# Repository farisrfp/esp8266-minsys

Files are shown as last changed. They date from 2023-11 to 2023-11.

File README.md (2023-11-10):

# **ESP8266 Minimum System**

_Workshop Telematika 2023_

Teknik Komputer ITS

## **Deskripsi**

Dokumentasi ini dibuat untuk memudahkan peserta workshop dalam memahami dan mengembangkan ESP8266 Minimum System pada Workshop Telematika 2023.

Diagram Fitur ESP8266 Minimum System dan PCB dapat dilihat pada gambar berikut.

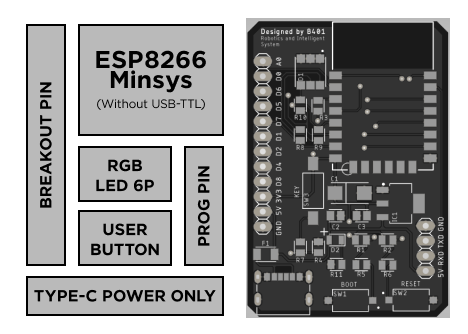
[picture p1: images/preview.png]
ESP8266 Minimum System


## Hardware

Gambar dibawah merupakan design hardware ESP8266 Minimum System yang akan digunakan pada workshop.

<table>
                <tr>
                    <th>Jalur PCB</th>
                    <th>Hasil Gerber</th>
                    <th>Gambar 3D</th>
                </tr>
                <tr>
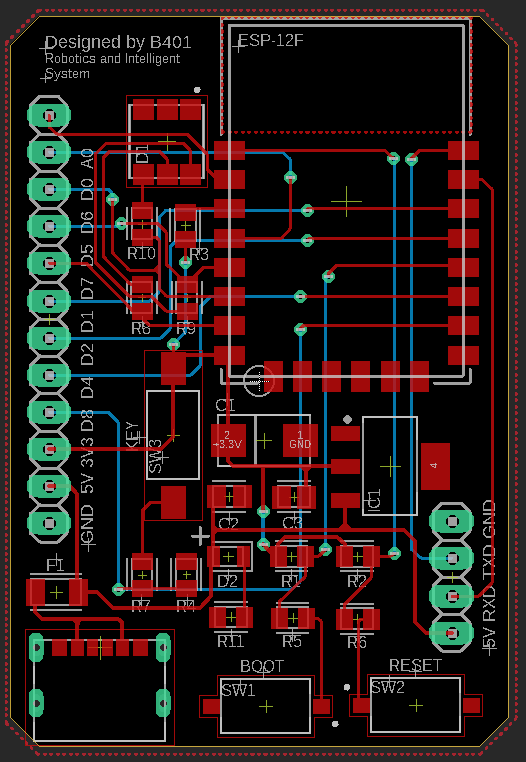
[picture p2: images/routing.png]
                    <td></td>
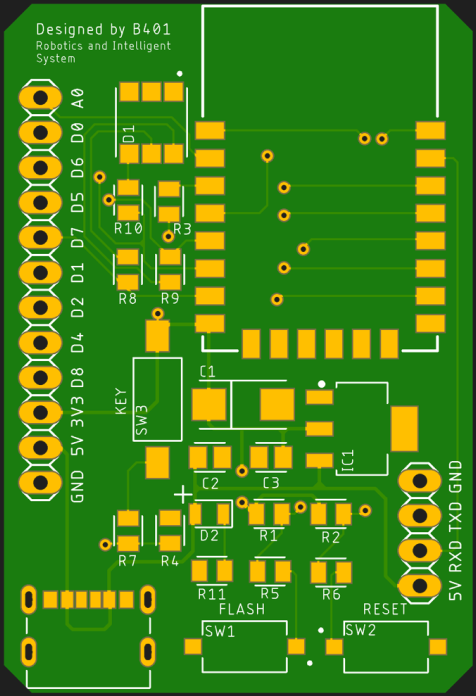
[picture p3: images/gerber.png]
                    <td></td>
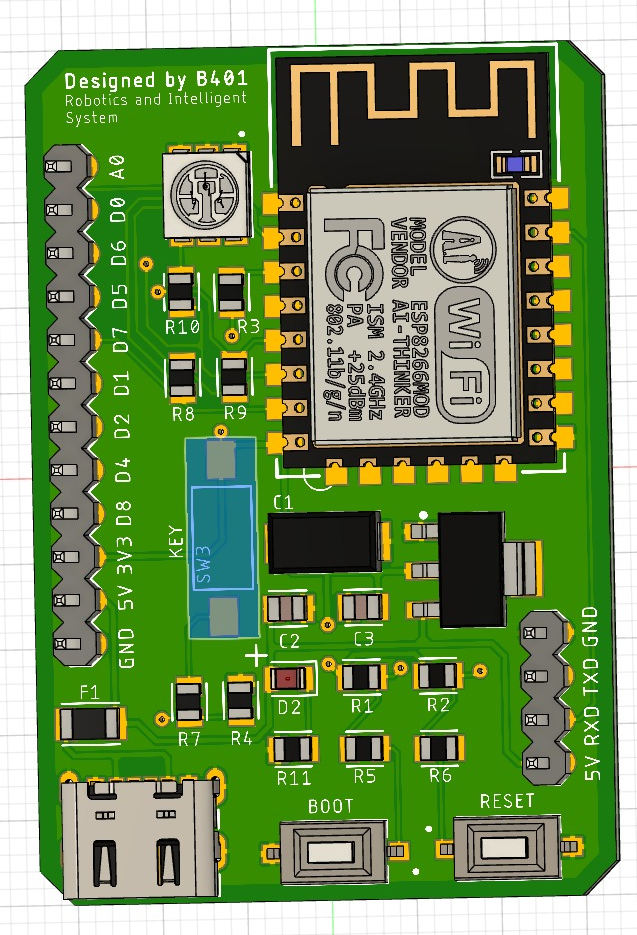
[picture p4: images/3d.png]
                    <td></td>
                </tr>
</table>

Untuk dokumentasi hardware, silahkan lihat [/hardware](hardware/readme.md)

## Firmware

Untuk dokumentasi firmware, silahkan lihat [/firmware](firmware/readme.md)

## Kontribusi

Kami sangat terbuka terhadap kontribusi dari semua pihak. Jika Anda ingin berkontribusi dengan memperbaiki atau melengkapi template ini, silakan buat pull request ke repositori template kami.

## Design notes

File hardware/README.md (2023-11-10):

# **Dokumentasi Hardware**

## Software

- [Eagle](https://www.autodesk.com/products/eagle/overview) (Untuk membuka file .sch dan .brd)
- [Fusion 360](https://www.autodesk.com/products/fusion-360/overview) (Alternatif)

## Schematic

Gambar dibawah merupakan schematic ESP8266 Minimum System yang akan digunakan pada workshop.

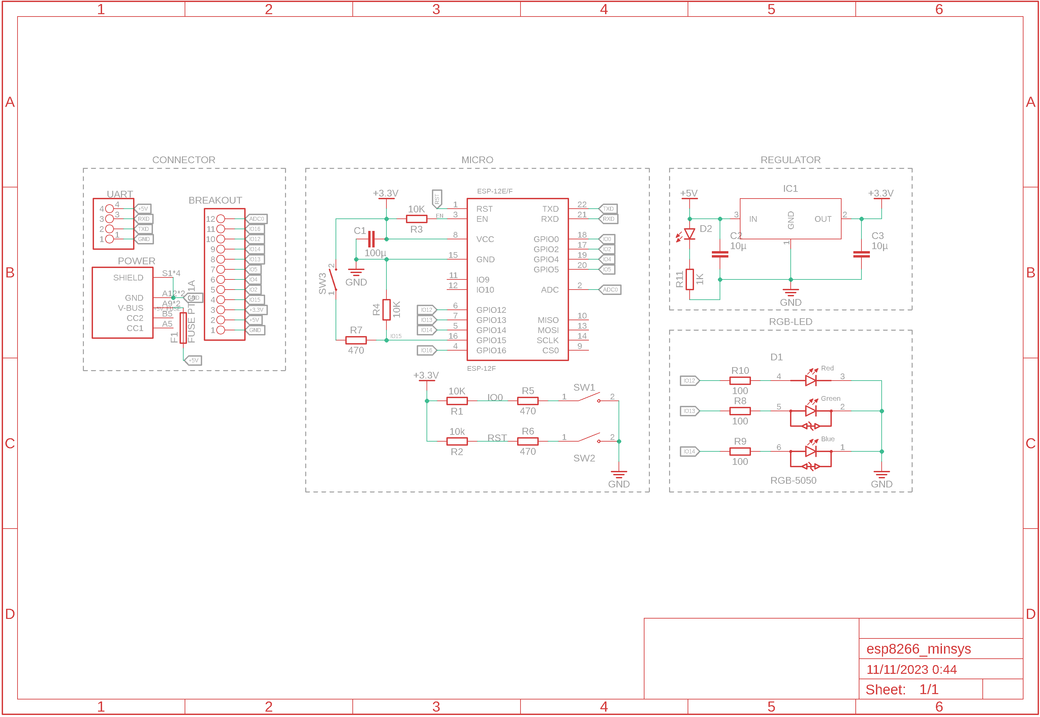
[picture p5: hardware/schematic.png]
Schematic


## Bill of Material

| Designator | Quantity | Package | Value | Description |
| :---: | :---: | :-----: | :---: | :---: |
|  R1 - R4 | 4 |  0805 |  10K  | Resistor |
|  R5 - R7 | 3 |  0805 |  330  | Resistor |
|  R8 - R10  | 3 |  0805 |  100  | Resistor |
| R11 | 1 |  0805 |  1K | Resistor |
| C1 | 1 |  2412 | 100u  | Kapasitor |
|  C2 - C3 | 2 |  0805 |  10u  | Kapasitor |
| D1 | 1 |  5050 |  RGB  | LED |
| D2 | 1 |  0805 |  Red  | LED |
| SW1 | 1 | - | - | Push Button (1) |
| SW2 - SW3  | 1 | - | - | Push Button (2) |
| IC1 | 1 | SOT-223 |  3V3  | Voltage Regulator 3V3 |
| F1 | 1 |  1206 | 750mA | Fuse |
| J1 | 1 | - |  6P | USB Type-C |

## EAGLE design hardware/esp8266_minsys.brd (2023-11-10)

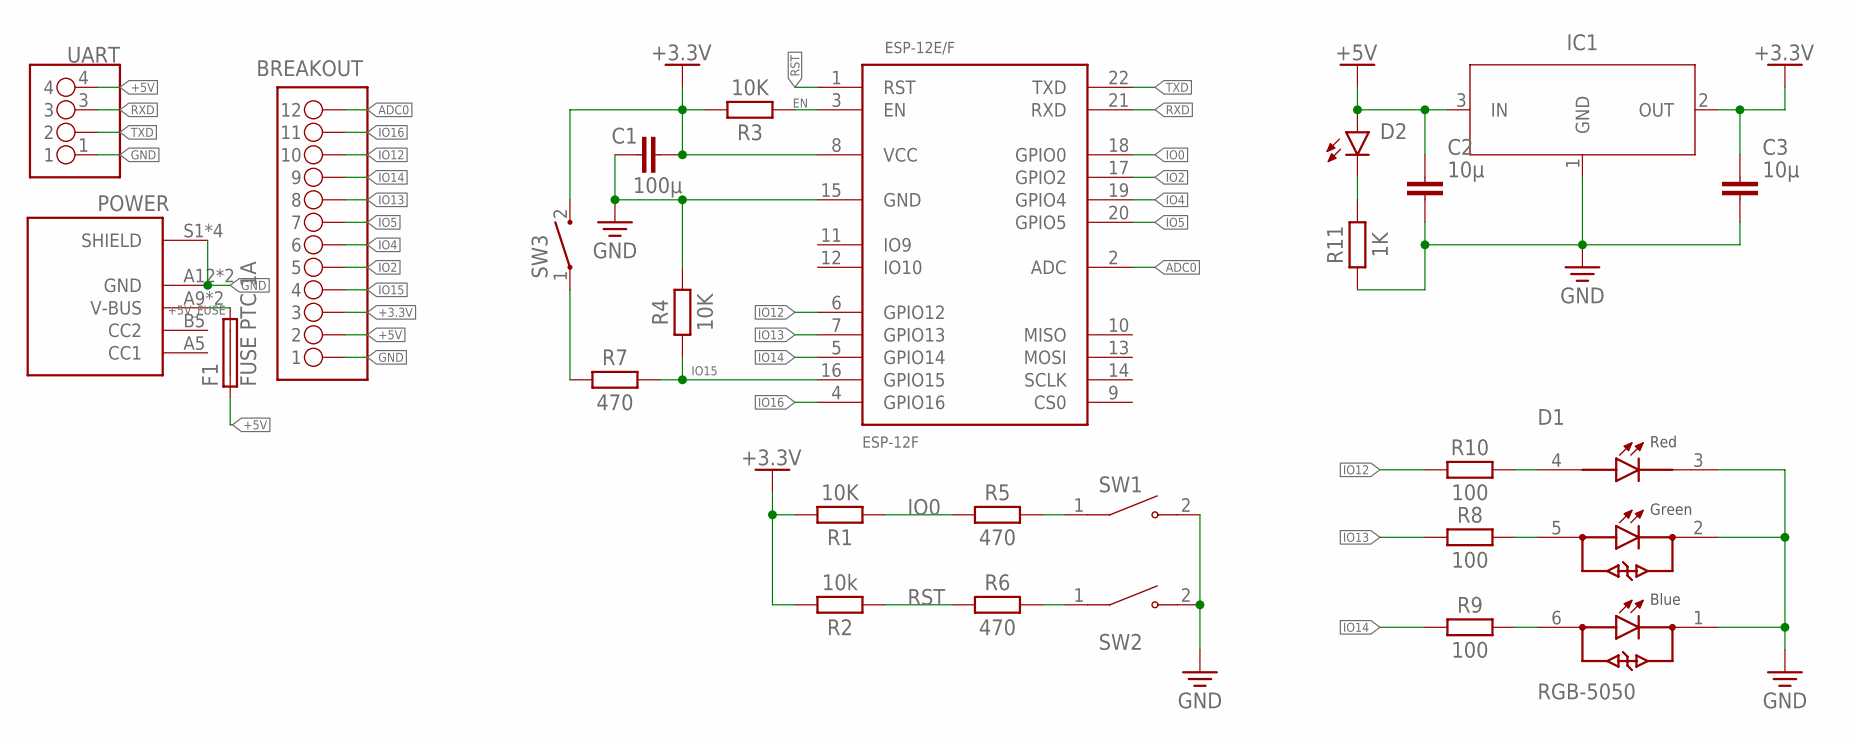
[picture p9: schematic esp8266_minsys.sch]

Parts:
BREAKOUT: PINHD-1X12-BACKUP_1X12M; 1X12
C1: 100µ; CAPM6032X280
C2, C3: 10µ; CAPC2012X110
D1: RGB-5050
D2: LED_RED; LEDC2012X110N_FLAT-R
ESP-12E/F: ESP-12F
F1: FUSE PTC 1A; FUSC3215X82N
IC1: NCP1117ST33T3G; SOT230P700X170-4
POWER: SOCKET-C
R1, R3, R4: 10K; RESC2012X65
R2: 10k; RESC2012X65
R5, R6, R7: 470; RESC2012X65
R8, R9, R10: 100; RESC2012X65
R11: 1K; RESC2012X65
SW1, SW2: SWITCH-2P
SW3: SWITCH; SW_1437566-3
UART: PINHD-1X04_1X04M; 1X04

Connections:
+3.3V: BREAKOUT.3, C1.2, C3.1, ESP-12E/F.8 (VCC), IC1.2 (OUT), R1.2, R2.2, R3.2, SW3.2
+5V: BREAKOUT.2, C2.1, D2.A, F1.1, IC1.3 (IN), UART.4
+5V_FUSE: F1.2, POWER.A9 (V-BUS), POWER.B9 (V-BUS)
ADC0: BREAKOUT.12, ESP-12E/F.2 (ADC)
EN: ESP-12E/F.3 (EN), R3.1
GND: BREAKOUT.1, C1.1, C2.2, C3.2, D1.1, D1.2, D1.3, ESP-12E/F.15 (GND), IC1.1 (GND), POWER.A12 (GND), POWER.B12 (GND), POWER.S1 (SHIELD), POWER.S2 (SHIELD), POWER.S3 (SHIELD), POWER.S4 (SHIELD), R4.2, R11.1, SW1.2, SW2.2, UART.1
IO0: ESP-12E/F.18 (GPIO0), R1.1, R5.1
IO2: BREAKOUT.5, ESP-12E/F.17 (GPIO2)
IO4: BREAKOUT.6, ESP-12E/F.19 (GPIO4)
IO5: BREAKOUT.7, ESP-12E/F.20 (GPIO5)
IO12: BREAKOUT.10, ESP-12E/F.6 (GPIO12), R10.1
IO13: BREAKOUT.8, ESP-12E/F.7 (GPIO13), R8.1
IO14: BREAKOUT.9, ESP-12E/F.5 (GPIO14), R9.1
IO15: BREAKOUT.4, ESP-12E/F.16 (GPIO15), R4.1, R7.2
IO16: BREAKOUT.11, ESP-12E/F.4 (GPIO16)
unnamed: D1.4, R10.2
unnamed: D1.5, R8.2
unnamed: D1.6, R9.2
unnamed: R5.2, SW1.1
unnamed: R6.2, SW2.1
unnamed: R7.1, SW3.1
unnamed: D2.C, R11.2
RST: ESP-12E/F.1 (RST), R2.1, R6.1
RXD: ESP-12E/F.21 (RXD), UART.3
TXD: ESP-12E/F.22 (TXD), UART.2

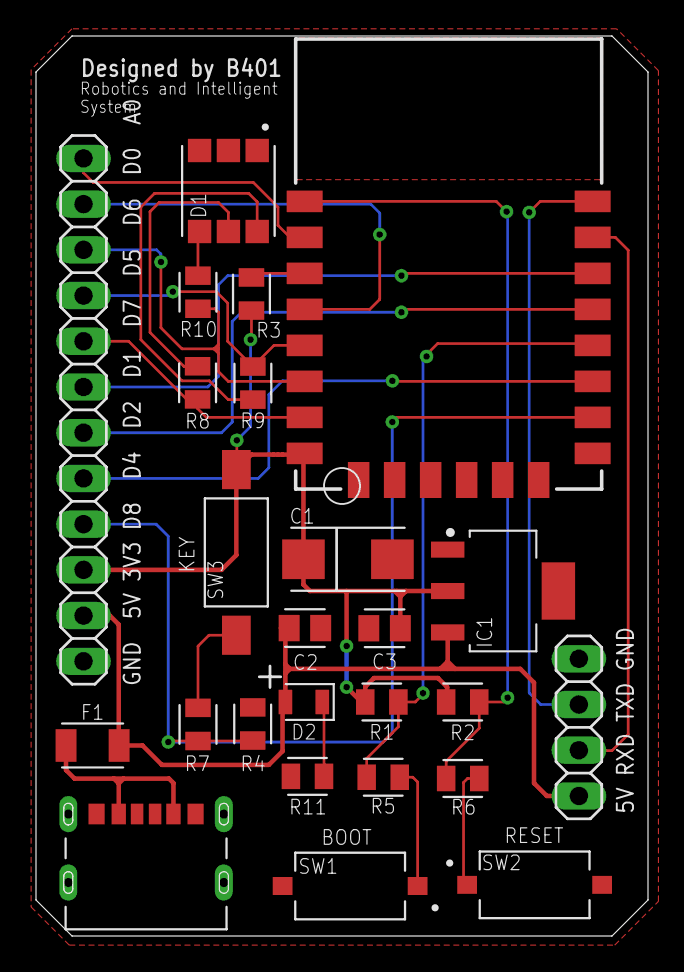
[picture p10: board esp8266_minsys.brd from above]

Board: 2 copper layers, 34.0 x 50.0 mm, 25 parts (0 on the bottom side), 25 nets.

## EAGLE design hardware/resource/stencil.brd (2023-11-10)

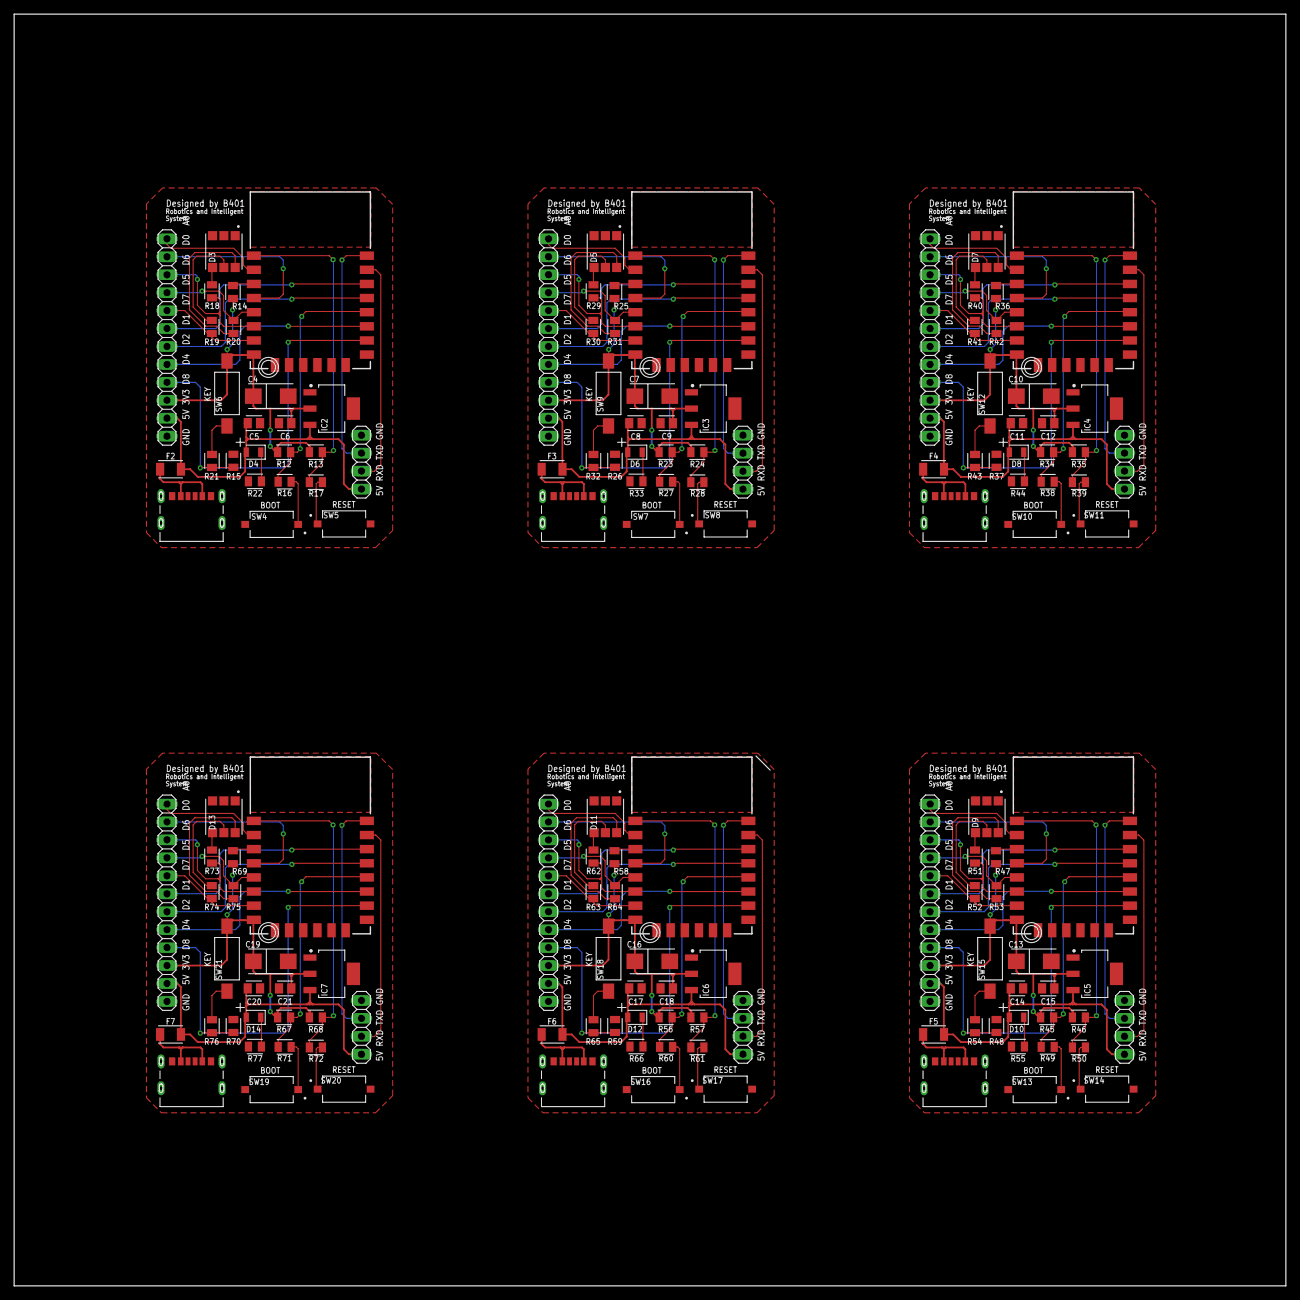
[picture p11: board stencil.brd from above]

Board: 2 copper layers, 180.0 x 180.0 mm, 150 parts (0 on the bottom side), 150 nets.

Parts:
BREAKOUT1, BREAKOUT2, BREAKOUT3, BREAKOUT4, BREAKOUT5, BREAKOUT6: PINHD-1X12-BACKUP_1X12M; 1X12
C4, C7, C10, C13, C16, C19: 100µ; CAPM6032X280
C5, C6, C8, C9, C11, C12, C14, C15, C17, C18, C20, C21: 10µ; CAPC2012X110
D3, D5, D7, D9, D11, D13: RGB-5050
D4, D6, D8, D10, D12, D14: LED_RED; LEDC2012X110N_FLAT-R
ESP-12E/F1, ESP-12E/F2, ESP-12E/F3, ESP-12E/F4, ESP-12E/F5, ESP-12E/F6: ESP-12F
F2, F3, F4, F5, F6, F7: FUSE PTC 1A; FUSC3215X82N
IC2, IC3, IC4, IC5, IC6, IC7: NCP1117ST33T3G; SOT230P700X170-4
POWER1, POWER2, POWER3, POWER4, POWER5, POWER6: SOCKET-C
R12, R14, R15, R23, R25, R26, R34, R36, R37, R45, R47, R48, R56, R58, R59, R67, R69, R70: 10K; RESC2012X65
R13, R24, R35, R46, R57, R68: 10k; RESC2012X65
R16, R17, R21, R27, R28, R32, R38, R39, R43, R49, R50, R54, R60, R61, R65, R71, R72, R76: 470; RESC2012X65
R18, R19, R20, R22, R29, R30, R31, R33, R40, R41, R42, R44, R51, R52, R53, R55, R62, R63, R64, R66, R73, R74, R75, R77: 100; RESC2012X65
SW4, SW5, SW7, SW8, SW10, SW11, SW13, SW14, SW16, SW17, SW19, SW20: SWITCH-2P
SW6, SW9, SW12, SW15, SW18, SW21: SWITCH; SW_1437566-3
UART1, UART2, UART3, UART4, UART5, UART6: PINHD-1X04_1X04M; 1X04

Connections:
+3.3V1: BREAKOUT1.3, C4.2, C6.1, ESP-12E/F1.8, IC2.2, R12.2, R13.2, R14.2, SW6.2
+3.3V2: BREAKOUT2.3, C7.2, C9.1, ESP-12E/F2.8, IC3.2, R23.2, R24.2, R25.2, SW9.2
+3.3V3: BREAKOUT3.3, C10.2, C12.1, ESP-12E/F3.8, IC4.2, R34.2, R35.2, R36.2, SW12.2
+3.3V4: BREAKOUT4.3, C13.2, C15.1, ESP-12E/F4.8, IC5.2, R45.2, R46.2, R47.2, SW15.2
+3.3V5: BREAKOUT5.3, C16.2, C18.1, ESP-12E/F5.8, IC6.2, R56.2, R57.2, R58.2, SW18.2
+3.3V6: BREAKOUT6.3, C19.2, C21.1, ESP-12E/F6.8, IC7.2, R67.2, R68.2, R69.2, SW21.2
+5V1: BREAKOUT1.2, C5.1, D4.A, F2.1, IC2.3, UART1.4
+5V2: BREAKOUT2.2, C8.1, D6.A, F3.1, IC3.3, UART2.4
+5V3: BREAKOUT3.2, C11.1, D8.A, F4.1, IC4.3, UART3.4
+5V4: BREAKOUT4.2, C14.1, D10.A, F5.1, IC5.3, UART4.4
+5V5: BREAKOUT5.2, C17.1, D12.A, F6.1, IC6.3, UART5.4
+5V6: BREAKOUT6.2, C20.1, D14.A, F7.1, IC7.3, UART6.4
+5V_FUSE1: F2.2, POWER1.A9, POWER1.B9
+5V_FUSE2: F3.2, POWER2.A9, POWER2.B9
+5V_FUSE3: F4.2, POWER3.A9, POWER3.B9
+5V_FUSE4: F5.2, POWER4.A9, POWER4.B9
+5V_FUSE5: F6.2, POWER5.A9, POWER5.B9
+5V_FUSE6: F7.2, POWER6.A9, POWER6.B9
ADC1: BREAKOUT1.12, ESP-12E/F1.2
ADC2: BREAKOUT2.12, ESP-12E/F2.2
ADC3: BREAKOUT3.12, ESP-12E/F3.2
ADC4: BREAKOUT4.12, ESP-12E/F4.2
ADC5: BREAKOUT5.12, ESP-12E/F5.2
ADC6: BREAKOUT6.12, ESP-12E/F6.2
EN1: ESP-12E/F1.3, R14.1
EN2: ESP-12E/F2.3, R25.1
EN3: ESP-12E/F3.3, R36.1
EN4: ESP-12E/F4.3, R47.1
EN5: ESP-12E/F5.3, R58.1
EN6: ESP-12E/F6.3, R69.1
GND1: BREAKOUT1.1, C4.1, C5.2, C6.2, D3.1, D3.2, D3.3, ESP-12E/F1.15, IC2.1, POWER1.A12, POWER1.B12, POWER1.S1, POWER1.S2, POWER1.S3, POWER1.S4, R15.2, R22.1, SW4.2, SW5.2, UART1.1
GND2: BREAKOUT2.1, C7.1, C8.2, C9.2, D5.1, D5.2, D5.3, ESP-12E/F2.15, IC3.1, POWER2.A12, POWER2.B12, POWER2.S1, POWER2.S2, POWER2.S3, POWER2.S4, R26.2, R33.1, SW7.2, SW8.2, UART2.1
GND3: BREAKOUT3.1, C10.1, C11.2, C12.2, D7.1, D7.2, D7.3, ESP-12E/F3.15, IC4.1, POWER3.A12, POWER3.B12, POWER3.S1, POWER3.S2, POWER3.S3, POWER3.S4, R37.2, R44.1, SW10.2, SW11.2, UART3.1
GND4: BREAKOUT4.1, C13.1, C14.2, C15.2, D9.1, D9.2, D9.3, ESP-12E/F4.15, IC5.1, POWER4.A12, POWER4.B12, POWER4.S1, POWER4.S2, POWER4.S3, POWER4.S4, R48.2, R55.1, SW13.2, SW14.2, UART4.1
GND5: BREAKOUT5.1, C16.1, C17.2, C18.2, D11.1, D11.2, D11.3, ESP-12E/F5.15, IC6.1, POWER5.A12, POWER5.B12, POWER5.S1, POWER5.S2, POWER5.S3, POWER5.S4, R59.2, R66.1, SW16.2, SW17.2, UART5.1
GND6: BREAKOUT6.1, C19.1, C20.2, C21.2, D13.1, D13.2, D13.3, ESP-12E/F6.15, IC7.1, POWER6.A12, POWER6.B12, POWER6.S1, POWER6.S2, POWER6.S3, POWER6.S4, R70.2, R77.1, SW19.2, SW20.2, UART6.1
IO1: ESP-12E/F1.18, R12.1, R16.1
IO3: BREAKOUT1.10, ESP-12E/F1.6, R18.1
IO6: BREAKOUT1.8, ESP-12E/F1.7, R19.1
IO7: BREAKOUT1.9, ESP-12E/F1.5, R20.1
IO8: BREAKOUT1.6, ESP-12E/F1.19
IO9: BREAKOUT1.7, ESP-12E/F1.20
IO10: BREAKOUT1.11, ESP-12E/F1.4
IO11: BREAKOUT1.5, ESP-12E/F1.17
IO17: BREAKOUT1.4, ESP-12E/F1.16, R15.1, R21.2
IO18: ESP-12E/F2.18, R23.1, R27.1
IO19: BREAKOUT2.10, ESP-12E/F2.6, R29.1
IO20: BREAKOUT2.8, ESP-12E/F2.7, R30.1
IO21: BREAKOUT2.9, ESP-12E/F2.5, R31.1
IO22: BREAKOUT2.6, ESP-12E/F2.19
IO23: BREAKOUT2.7, ESP-12E/F2.20
IO24: BREAKOUT2.11, ESP-12E/F2.4
IO25: BREAKOUT2.5, ESP-12E/F2.17
IO26: BREAKOUT2.4, ESP-12E/F2.16, R26.1, R32.2
IO27: ESP-12E/F3.18, R34.1, R38.1
IO28: BREAKOUT3.10, ESP-12E/F3.6, R40.1
IO29: BREAKOUT3.8, ESP-12E/F3.7, R41.1
IO30: BREAKOUT3.9, ESP-12E/F3.5, R42.1
IO31: BREAKOUT3.6, ESP-12E/F3.19
IO32: BREAKOUT3.7, ESP-12E/F3.20
IO33: BREAKOUT3.11, ESP-12E/F3.4
IO34: BREAKOUT3.5, ESP-12E/F3.17
IO35: BREAKOUT3.4, ESP-12E/F3.16, R37.1, R43.2
IO36: ESP-12E/F4.18, R45.1, R49.1
IO37: BREAKOUT4.10, ESP-12E/F4.6, R51.1
IO38: BREAKOUT4.8, ESP-12E/F4.7, R52.1
IO39: BREAKOUT4.9, ESP-12E/F4.5, R53.1
IO40: BREAKOUT4.6, ESP-12E/F4.19
IO41: BREAKOUT4.7, ESP-12E/F4.20
IO42: BREAKOUT4.11, ESP-12E/F4.4
IO43: BREAKOUT4.5, ESP-12E/F4.17
IO44: BREAKOUT4.4, ESP-12E/F4.16, R48.1, R54.2
IO45: ESP-12E/F5.18, R56.1, R60.1
IO46: BREAKOUT5.10, ESP-12E/F5.6, R62.1
IO47: BREAKOUT5.8, ESP-12E/F5.7, R63.1
IO48: BREAKOUT5.9, ESP-12E/F5.5, R64.1
IO49: BREAKOUT5.6, ESP-12E/F5.19
IO50: BREAKOUT5.7, ESP-12E/F5.20
IO51: BREAKOUT5.11, ESP-12E/F5.4
IO52: BREAKOUT5.5, ESP-12E/F5.17
IO53: BREAKOUT5.4, ESP-12E/F5.16, R59.1, R65.2
IO54: ESP-12E/F6.18, R67.1, R71.1
IO55: BREAKOUT6.10, ESP-12E/F6.6, R73.1
IO56: BREAKOUT6.8, ESP-12E/F6.7, R74.1
IO57: BREAKOUT6.9, ESP-12E/F6.5, R75.1
IO58: BREAKOUT6.6, ESP-12E/F6.19
IO59: BREAKOUT6.7, ESP-12E/F6.20
IO60: BREAKOUT6.11, ESP-12E/F6.4
IO61: BREAKOUT6.5, ESP-12E/F6.17
IO62: BREAKOUT6.4, ESP-12E/F6.16, R70.1, R76.2
unnamed: R16.2, SW4.1
unnamed: R17.2, SW5.1
unnamed: D3.4, R18.2
unnamed: D3.5, R19.2
unnamed: D3.6, R20.2
unnamed: R21.1, SW6.1
unnamed: D4.C, R22.2
unnamed: R27.2, SW7.1
unnamed: R28.2, SW8.1
unnamed: D5.4, R29.2
unnamed: D5.5, R30.2
unnamed: D5.6, R31.2
unnamed: R32.1, SW9.1
unnamed: D6.C, R33.2
unnamed: R38.2, SW10.1
unnamed: R39.2, SW11.1
unnamed: D7.4, R40.2
unnamed: D7.5, R41.2
unnamed: D7.6, R42.2
unnamed: R43.1, SW12.1
unnamed: D8.C, R44.2
unnamed: R49.2, SW13.1
unnamed: R50.2, SW14.1
unnamed: D9.4, R51.2
unnamed: D9.5, R52.2
unnamed: D9.6, R53.2
unnamed: R54.1, SW15.1
unnamed: D10.C, R55.2
unnamed: R60.2, SW16.1
unnamed: R61.2, SW17.1
unnamed: D11.4, R62.2
unnamed: D11.5, R63.2
unnamed: D11.6, R64.2
unnamed: R65.1, SW18.1
unnamed: D12.C, R66.2
unnamed: R71.2, SW19.1
unnamed: R72.2, SW20.1
unnamed: D13.4, R73.2
unnamed: D13.5, R74.2
unnamed: D13.6, R75.2
unnamed: R76.1, SW21.1
unnamed: D14.C, R77.2
RST1: ESP-12E/F1.1, R13.1, R17.1
RST2: ESP-12E/F2.1, R24.1, R28.1
RST3: ESP-12E/F3.1, R35.1, R39.1
RST4: ESP-12E/F4.1, R46.1, R50.1
RST5: ESP-12E/F5.1, R57.1, R61.1
RST6: ESP-12E/F6.1, R68.1, R72.1
RXD1: ESP-12E/F1.21, UART1.3
RXD2: ESP-12E/F2.21, UART2.3
RXD3: ESP-12E/F3.21, UART3.3
RXD4: ESP-12E/F4.21, UART4.3
RXD5: ESP-12E/F5.21, UART5.3
RXD6: ESP-12E/F6.21, UART6.3
TXD1: ESP-12E/F1.22, UART1.2
TXD2: ESP-12E/F2.22, UART2.2
TXD3: ESP-12E/F3.22, UART3.2
TXD4: ESP-12E/F4.22, UART4.2
TXD5: ESP-12E/F5.22, UART5.2
TXD6: ESP-12E/F6.22, UART6.2

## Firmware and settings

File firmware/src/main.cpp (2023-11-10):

/**
 * @file main.cpp
 * @brief Main program body
 * @version 0.1
 * @date 2023-11-05
 * @author b401
 *
 * This is an OTA firmware for ESP8266
 * The ESP8266 will act as an access point without password
 * To update the firmware, connect to the access point and open the IP address in the browser
 * The IP address is 11.4.0.1
 * Just upload the firmware located on ./.pio/build/[board]/firmware.bin and wait for the ESP8266 to reboot
 *
 */

#include <Arduino.h>
#include "LittleFS.h"
#include <DNSServer.h>
#include <ElegantOTA.h>
#include <ESP8266WiFi.h>
#include <ESP8266WebServer.h>

#define NETMASK_24 IPAddress(255, 255, 255, 0)
#define LED_PIN 2
#define RGB_LED_PIN_RED 15
#define RGB_LED_PIN_GREEN 12
#define RGB_LED_PIN_BLUE 13
#define BUTTON_PIN 3

/* USER CODE BEGIN PM */
#define AP_SSID "Kelompok_01"
/* USER CODE END PM */

const byte DNS_PORT = 53;
IPAddress esp_32_ip(11, 4, 0, 1);
DNSServer dnsServer;
ESP8266WebServer webServer(80);

/* USER CODE BEGIN PV */
uint8_t led_color_rgb[3] = {0, 0, 0};
/* USER CODE END PV */

void init_pin();

void setup()
{
  WiFi.mode(WIFI_AP);
  WiFi.softAPConfig(esp_32_ip, esp_32_ip, NETMASK_24);
  WiFi.softAP(AP_SSID);

  // if DNSServer is started with "*" for domain name, it will reply with provided IP to all DNS request
  dnsServer.start(DNS_PORT, "*", esp_32_ip);

  // route handle here
  webServer.onNotFound([]()
                       {      
                        webServer.sendHeader("Content-Encoding", "gzip");
                        webServer.send_P(200, "text/html", (const char*)ELEGANT_HTML, sizeof(ELEGANT_HTML)); });

  ElegantOTA.begin(&webServer);

  webServer.begin();

  /* USER CODE BEGIN 2 */
  pinMode(LED_PIN, OUTPUT);
  /* USER CODE END 2 */
}

void loop()
{
  ElegantOTA.loop();
  dnsServer.processNextRequest();
  webServer.handleClient();

  /* USER CODE BEGIN 3 */
  static uint32_t last_time = 0;
  if (millis() - last_time > 1000)
  {
    last_time = millis();
    digitalWrite(LED_PIN, !digitalRead(LED_PIN));
  }
  /* USER CODE END 3 */
}

void init_pin()
{
  pinMode(RGB_LED_PIN_RED, OUTPUT);
  pinMode(RGB_LED_PIN_GREEN, OUTPUT);
  pinMode(RGB_LED_PIN_BLUE, OUTPUT);
  pinMode(BUTTON_PIN, INPUT);
  delay(1);
  digitalWrite(RGB_LED_PIN_RED, LOW);
  digitalWrite(RGB_LED_PIN_GREEN, LOW);
  digitalWrite(RGB_LED_PIN_BLUE, LOW);
}
